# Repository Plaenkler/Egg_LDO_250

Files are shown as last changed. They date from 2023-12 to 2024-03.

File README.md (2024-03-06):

# Egg LDO 250

<table>
  <tr>
    <td></td>
    <td></td>
  </tr>
</table>

## 📖 What is LDO 250?

The **LDO 250** is the first board in the modular **EGG** design series. The **EGG** series is a conceptual compilation of many different modules.
Modules are created from independent circuit parts which have repeatedly appeared in my PCB designs.
Each of my circuits starts with the voltage source which is why **LDO 250** provides a linear voltage regulator with a low dropout voltage and a maximum current of 250 mA.

## ⚡ Circuit diagram

Schematics

## 🔌 Components

### USB-C connector

The 6-pin USB-C connector *USB4135-GF-A* can be sufficient for power supply in scenarios where space is limited and only basic USB functions are required.
This simplified version of the standard USB-C connector provides the essential connections for the power supply and is therefore ideal for small IoT projects.

### Low-dropout regulator

The *MCP1700T-3302E_TT* is a suitable low dropout regulator (LDO) for IoT projects as it provides a stable 3.3V output voltage.
As an LDO, it enables efficient voltage regulation even with small differences between input and output voltage.
It is also characterized by protective functions such as thermal overload protection.

### Resistors

The *RK73B2ATTD512J* (5.1K resistors) are used on a USB-C port to designate the device as a Downstream Facing Device (DFD) or UFP (USB Type-C Female Plug).
This configuration signals to chargers or host devices that a device is connected that requires power.

### Capacitors

With the MCP1700T-3302E/TT, *C0805C106K8PACTU* (10 μF 10V) is used at both the input and output.
A capacitor is used at the input to stabilize the input voltage and filter high-frequency noise.
At the output, the capacitor is used to maintain a stable output voltage and to compensate for rapid load changes.

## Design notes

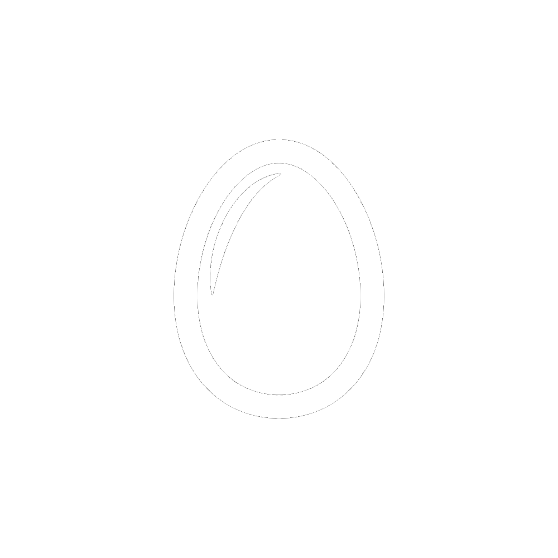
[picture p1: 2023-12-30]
Egg_LDO_250.kicad.png

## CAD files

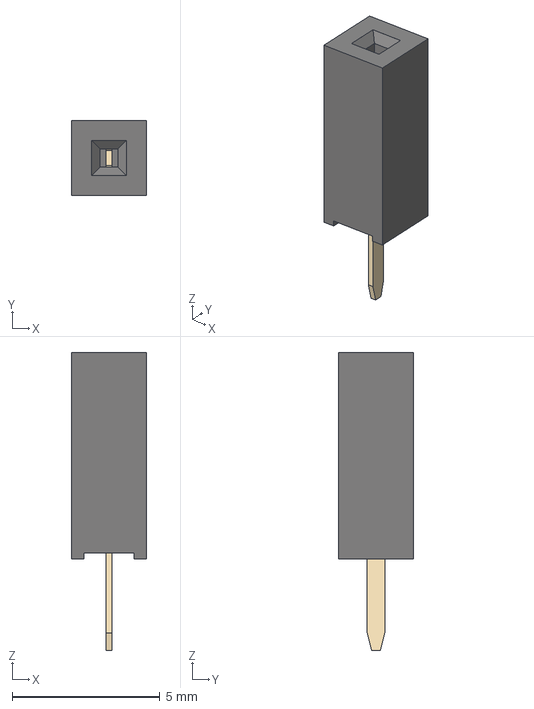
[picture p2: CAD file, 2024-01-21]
Egg_LDO_250_3D/PinSocket_1x01_P2.54mm_Vertical.step
2.54 x 2.54 x 10.1 mm

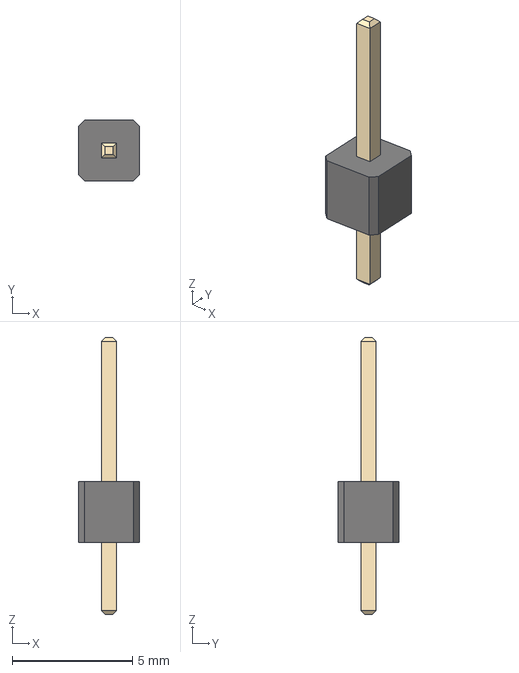
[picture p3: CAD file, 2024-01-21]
Egg_LDO_250_3D/PinHeader_1x01_P2.54mm_Vertical.step
2.54 x 2.54 x 11.5 mm

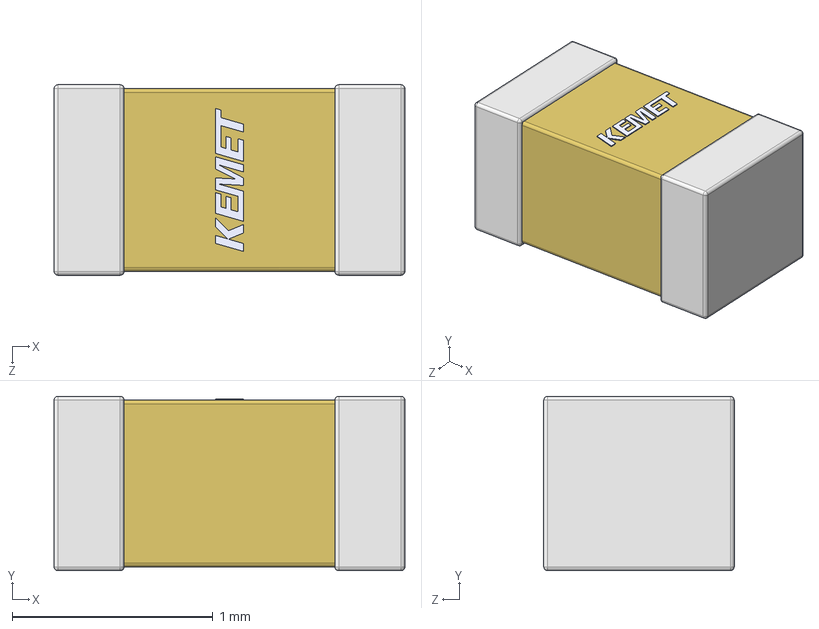
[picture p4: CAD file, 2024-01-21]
Egg_LDO_250_3D/C0603C106M8PAC7411.stp
1.75 x 0.87 x 0.95 mm

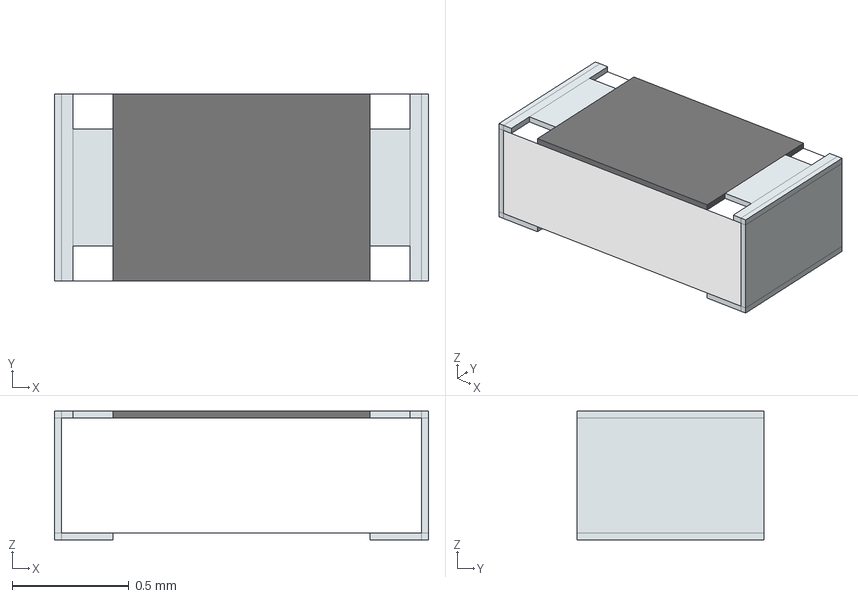
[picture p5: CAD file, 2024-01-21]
Egg_LDO_250_3D/ERJ-UP3J512V.stp
1.60 x 0.8 x 0.55 mm
solidBody
solidLead
solidTop

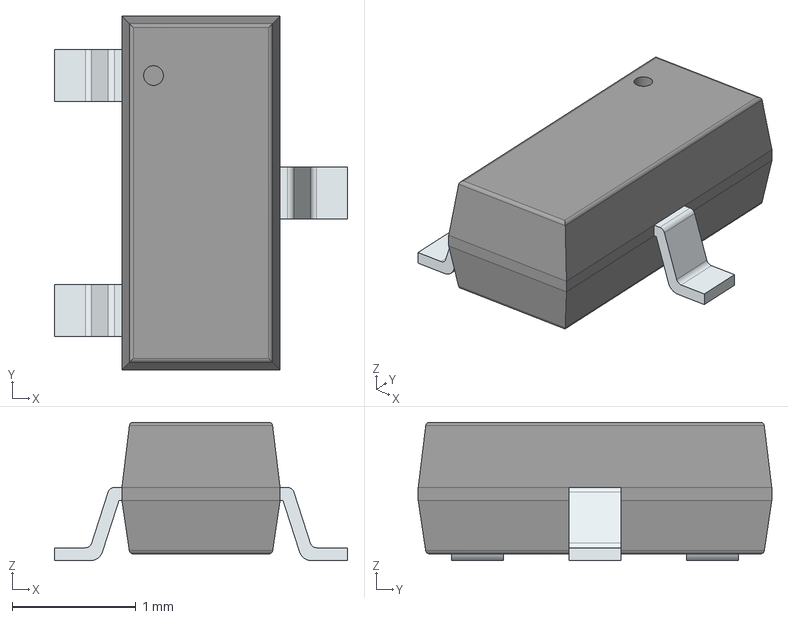
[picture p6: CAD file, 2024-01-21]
Egg_LDO_250_3D/MCP1700T-3302E_TT.stp
2.37 x 2.86 x 1.12 mm
PinsArrayL
FilletPinR

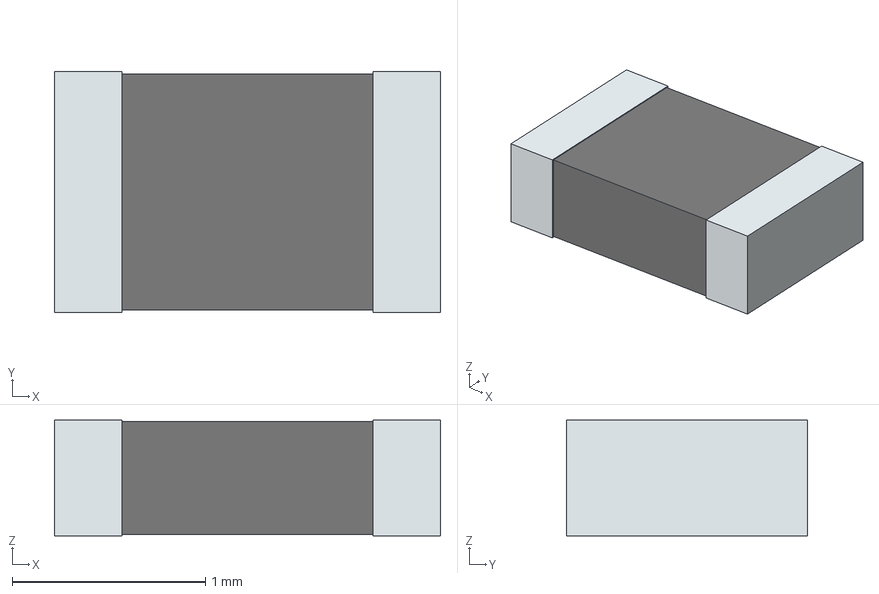
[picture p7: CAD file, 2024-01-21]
Egg_LDO_250_3D/RK73B2ATTD512J.stp
2.00 x 1.25 x 0.6 mm
term1
term2

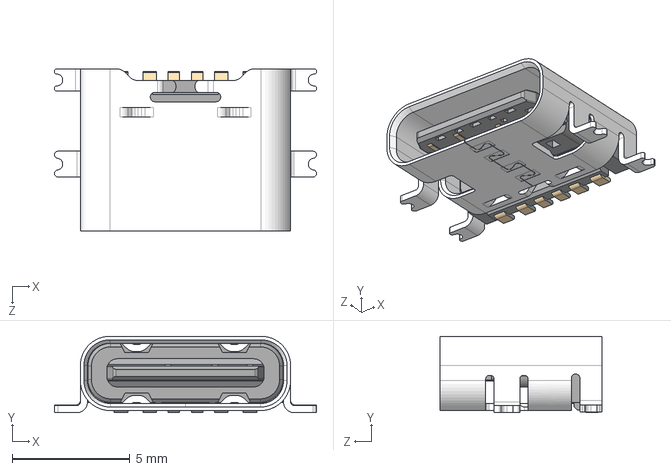
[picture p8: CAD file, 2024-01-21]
Egg_LDO_250_3D/USB4135-GF-A.stp
11.1 x 3.25 x 6.90 mm
USB4135-GF-A
USB4135-GF-A_2

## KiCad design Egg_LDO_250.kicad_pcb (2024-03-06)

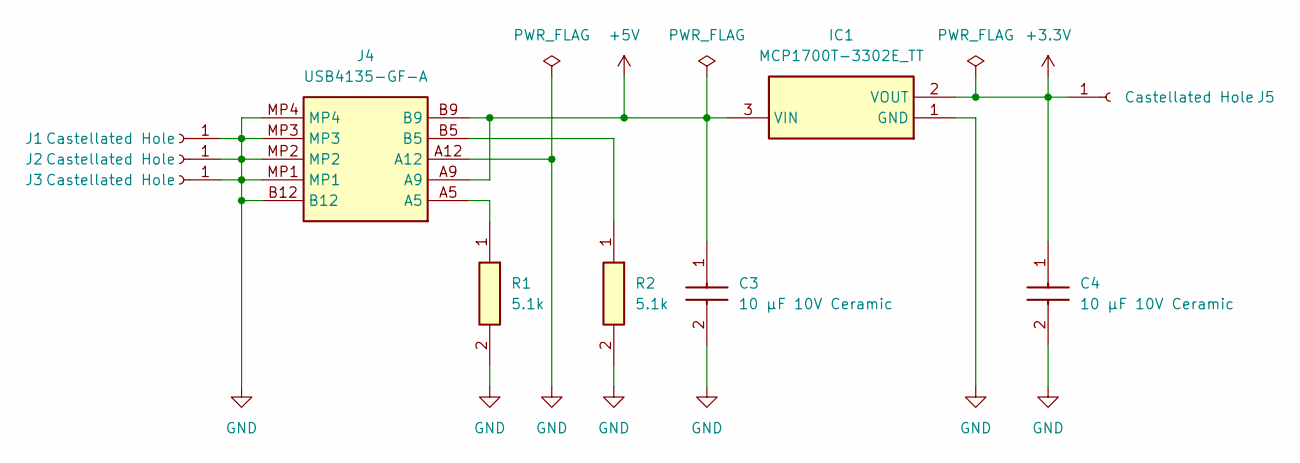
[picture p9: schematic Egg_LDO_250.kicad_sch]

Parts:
C3, C4: 10 μF 10V Ceramic; C0603; Mouser Part Number 80-C0603C106M8PLR
IC1: MCP1700T-3302E_TT; SOT95P237X112-3N; Mouser Part Number 579-MCP1700T3302E/TT
J1, J2, J3, J5: Castellated Hole; PinHeader_1x01_P2.54mm_Vertical
J4: USB4135-GF-A; USB4135GFA; Mouser Part Number 640-USB4135-GF-A
R1, R2: 5.1k; ERJUP3; Mouser Part Number 667-ERJ-UP3J512V

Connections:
+3.3V: C4.1, IC1.2 (VOUT), J5.1
+5V: C3.1, IC1.3 (VIN), J4.A9, J4.B9
GND: C3.2, C4.2, IC1.1 (GND), J1.1, J2.1, J3.1, J4.A12, J4.B12, J4.MP1, J4.MP2, J4.MP3, J4.MP4, R1.2, R2.2
unnamed: J4.A5, R1.1
unnamed: J4.B5, R2.1

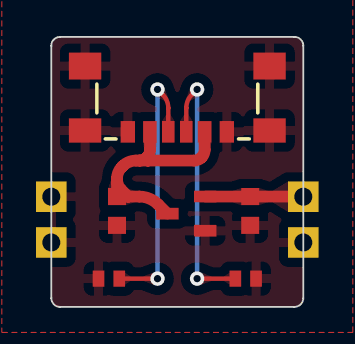
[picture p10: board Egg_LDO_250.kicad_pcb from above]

Board: 2 copper layers, 14.0 x 15.0 mm, 11 parts (1 on the bottom side), 5 nets.

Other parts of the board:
G1: LOGO; egg_logo

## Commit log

2023-12-30 [ADD] Current state
    [Egg_LDO.kicad_pcb, Egg_LDO.kicad_sch]
2023-12-31 [FIX] Placement on sheets
    [Egg_LDO.kicad_pcb, Egg_LDO.kicad_sch]
2024-01-01 [UPD] USB socket hangs over
    [Egg_LDO.kicad_pcb]
2024-01-14 [ADD] Interactive BOM
2024-01-21 [UPD] Several improvements
    - USB-C SMD only
    - 2.54 castellated holes
    - 0603 Resistors and capacitors
    [C0603C106M8PAC7411.stp, ERJ-UP3J512V.stp, Egg_LDO.kicad_pcb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]
2024-01-21 [UPD] Reworked PCB T&B routing
    [Egg_LDO_250.kicad_pcb]
2024-01-21 [ADD] Castellated hole 4
    [Egg_LDO_250.kicad_sch]
2024-01-21 [UPD] Routing and Silkscreen
    [Egg_LDO_250.kicad_pcb]
2024-01-21 [REM] Locking files
    [Egg_LDO_250.kicad_pcb]
2024-01-22 [FIX] Castellated pads
    [Egg_LDO_250.kicad_pcb]
2024-01-23 [UPD] BOM contents
2024-01-23 [FIX] Silkscreen version
    [Egg_LDO_250.kicad_pcb]
2024-03-06 [BCH] Migrated to KiCAD8
    - Added teardrops
    - Rounded traces
    [Egg_LDO_250.kicad_pcb, Egg_LDO_250.kicad_sch]

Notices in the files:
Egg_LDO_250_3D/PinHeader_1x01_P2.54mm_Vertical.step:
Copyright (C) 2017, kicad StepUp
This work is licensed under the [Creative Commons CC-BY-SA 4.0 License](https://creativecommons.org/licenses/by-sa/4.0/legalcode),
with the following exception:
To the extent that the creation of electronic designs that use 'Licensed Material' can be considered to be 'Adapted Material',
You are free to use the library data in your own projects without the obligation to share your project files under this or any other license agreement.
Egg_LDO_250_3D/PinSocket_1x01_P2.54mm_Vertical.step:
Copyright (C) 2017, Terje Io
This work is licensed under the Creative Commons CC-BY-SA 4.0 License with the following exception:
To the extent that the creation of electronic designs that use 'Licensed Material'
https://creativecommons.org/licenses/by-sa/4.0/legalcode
